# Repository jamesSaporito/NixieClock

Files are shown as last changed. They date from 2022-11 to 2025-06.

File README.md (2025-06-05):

# Nixie Clock Overview

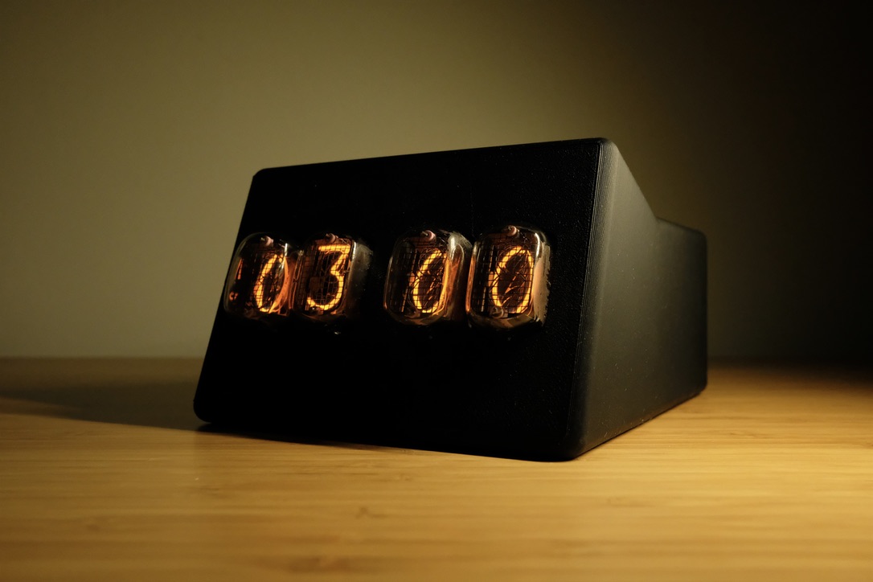
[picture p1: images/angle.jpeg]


This is a nixie tube clock that tells basic time. Two push buttons are used to set the time, one for the hour and the
other for the minute, and a mechanical switch turns the tubes on and off.

More info about [Nixie Tubes](https://en.wikipedia.org/wiki/Nixie_tube).

# Core Components

Four IN-12A nixie tubes are used, which require ~170V DC to illuminate. The
[NCH8200HV](https://omnixie.com/products/nch8200hv-nixie-hv-power-module)
is used to generate this voltage. The mechanical switch cuts power from this module, which allows the tubes to be turned
off.

The nixie tubes are driven from four [K155ID1](https://tubehobby.com/datasheets/k155id1.pdf) ICs, one IC per tube. These are very obsolete, but were made
specifically to drive nixie tubes. The microcontroller used for this project is the [STM32L010K4T6](https://www.st.com/en/microcontrollers-microprocessors/stm32l010k4.html), an Arm
Cortex-M0+ MCU. The RTC is used along with an external 32.768 kHz crystal to keep accurate time. Based on the one I've
built, it consistently gains around two seconds per day.

# PCB

The PCBs were designed using KiCad in two separate projects. These are found in the `pcb` directory.

There are two PCBs, the main board and the tube board. The main board is where all the main components live (MCU, ICs,
capacitors, etc.). The tube board is specifically for the tube sockets to be soldered to, and then the tubes to plug
into those. The main board and tube board plug into each other via header pins. The male header pins are soldered to one
board, and the female to the other. This is how the current flows from the main board to the tube board. It also allows
the PCBs to be disassembled if necessary.

## Notes

The tubes should not be directly soldered to the PCB. Instead, solder [tube sockets](https://www.amazon.com/Pieces-0-039inch-Diameter-Socket-Female/dp/B09D2VQR3Q?th=1)
to the PCB, then plug the tubes into those. This will allow replacement of a tube if one breaks.

# Enclosure

The `3d` directory contains the files for 3D printing an enclosure for the completely assembled clock. These parts
require [threaded brass inserts](https://www.amazon.com/gp/product/B07HKT5W7S/ref=ppx_yo_dt_b_asin_title_o04_s00?ie=UTF8&psc=1) for the screws to secure everything. There are currently two versions of the
enclosure.

## V1
Original design.

Screws are `M2.5 x 5` and `M2.5 x 8`.

The `PCB Spacers` are used for additional support between the boards to minimize stress on the header pins that connect
the tube board to the main board. Three of these spacers can be mounted while screwing the boards onto the front plate.

## V2
Inspired from Dieter Rams's design of the Braun DN40.

All screws are `M2.5 x 5`.

Four screws (top two alone are enough) can be used to secure the tube board to the `PCB Mount`. Easy to tap/screw
directly into the plastic.

The rest of the eight screws require the threaded brass inserts.

## Design Flaws

Due to the PCB using a Tag-Connect footprint for programming, the enclosure design pretty much requires the MCU to be
programmed prior to assembling everything. If there is a desire to upload different firmware, then it will mostly have
to be taken apart.

The DC jack that was used for this design requires to be mounted prior to soldering the wires to it. This restricts the
enclosure from being completely removed without cutting the wires to this jack.

# Firmware

The firmware is a standard STM32 project set up using CLion and its integration with STM32CubeMX.

The only important thing to keep some form of is the `cycle()` function, which is found in `Core/Src/nixie_display.c`.
All this does is cycle through each number on every tube, which is supposed to prevent cathode poisoning. Unsure how
effective this is at the current frequency and duration.

## Programming the MCU

In order to avoid additional hardware, a
[Tag-Connect](https://www.tag-connect.com/product/tc2030-idc-6-pin-tag-connect-plug-of-nails-spring-pin-cable-with-legs)
footprint is used on the main board. This is used with an
[ST-LINK](https://www.st.com/en/development-tools/st-link-v2.html)
device (clones should work just fine) to program the MCU.

### Issues

_Update: It looks like this issue was fixed, I have not had time to test it out._

Unfortunately, using 
[stlink](https://github.com/stlink-org/stlink)
doesn't seem to work with
[several STM32L0xxx MCUs](https://github.com/stlink-org/stlink/issues/1203).
To get around this, the project can be opened up in STM32CubeIDE and flashed using the built in debugging functionality.
Not ideal, but it works.

* STLink GitHub issue: [1203](https://github.com/stlink-org/stlink/issues/1203)

# Images

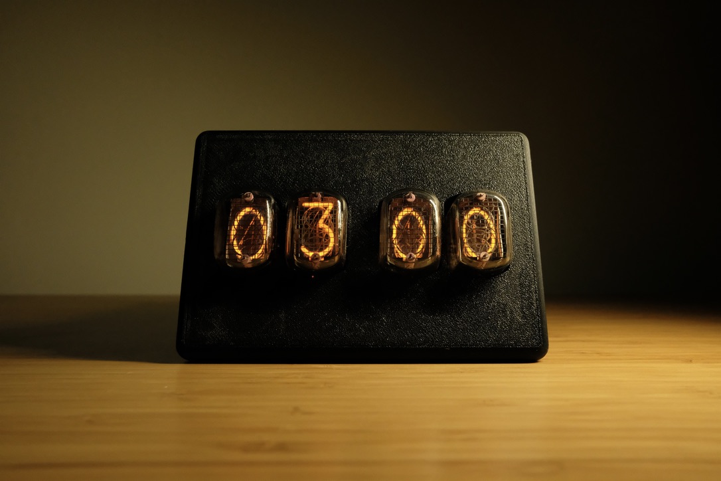
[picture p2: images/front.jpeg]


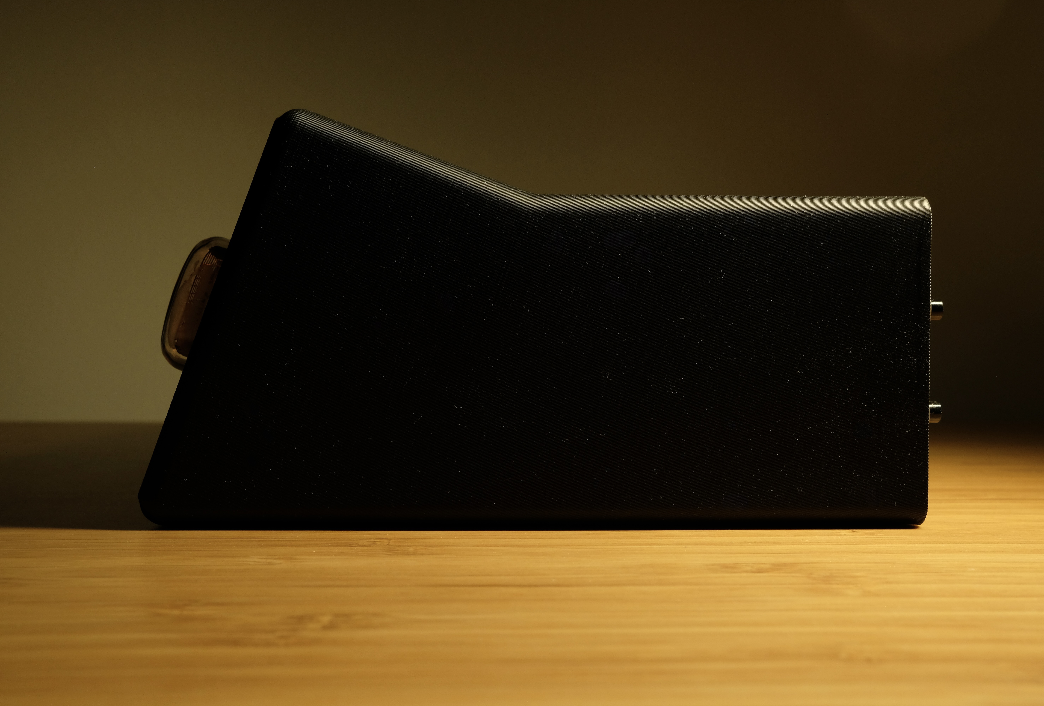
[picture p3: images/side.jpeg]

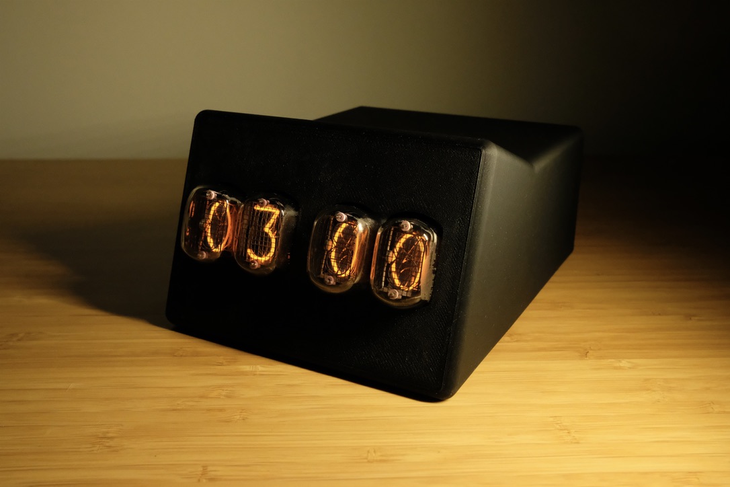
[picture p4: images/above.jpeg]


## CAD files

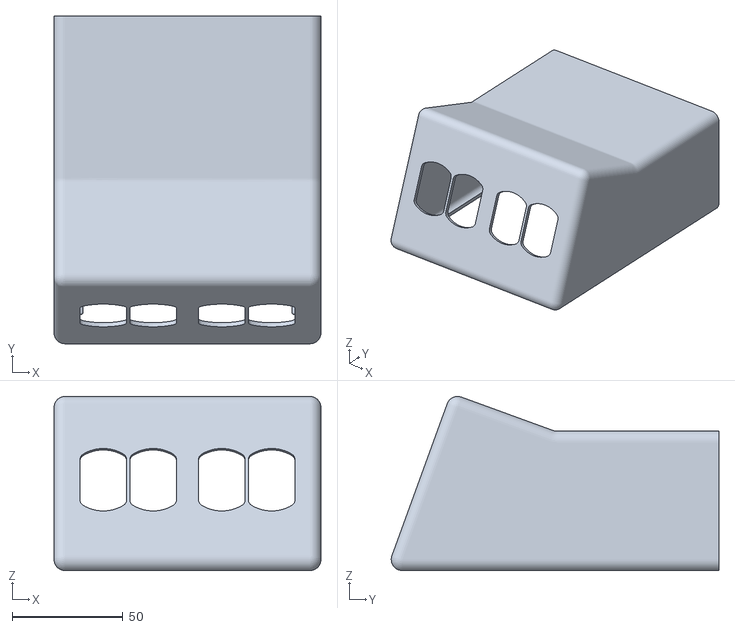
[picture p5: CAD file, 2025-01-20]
3d/v2/Main Body.stl
120.5 x 147.9 x 78.6

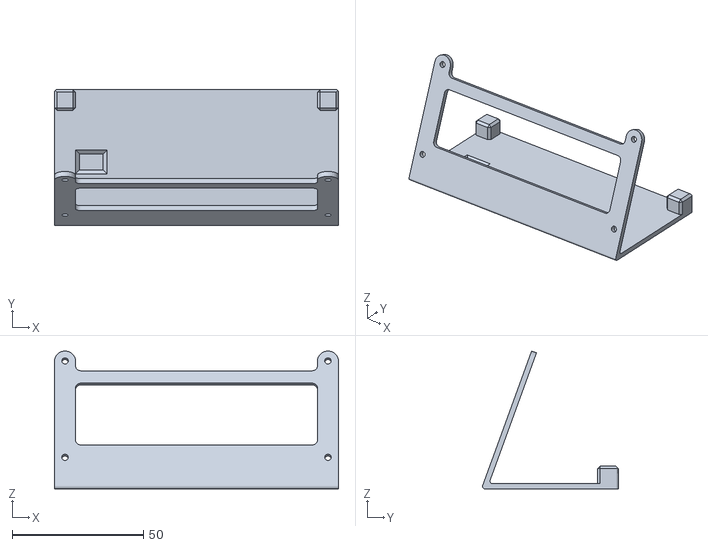
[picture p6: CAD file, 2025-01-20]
3d/v2/PCB Mount.stl
108.0 x 51.7 x 52.4

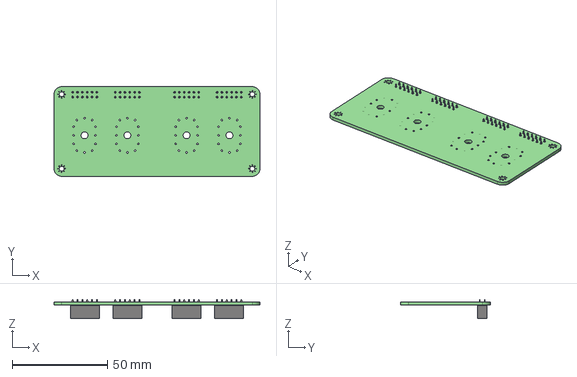
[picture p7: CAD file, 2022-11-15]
pcb/tube_board/Tube Board.step
108.0 x 47.0 x 10.1 mm
Tube Board PCB

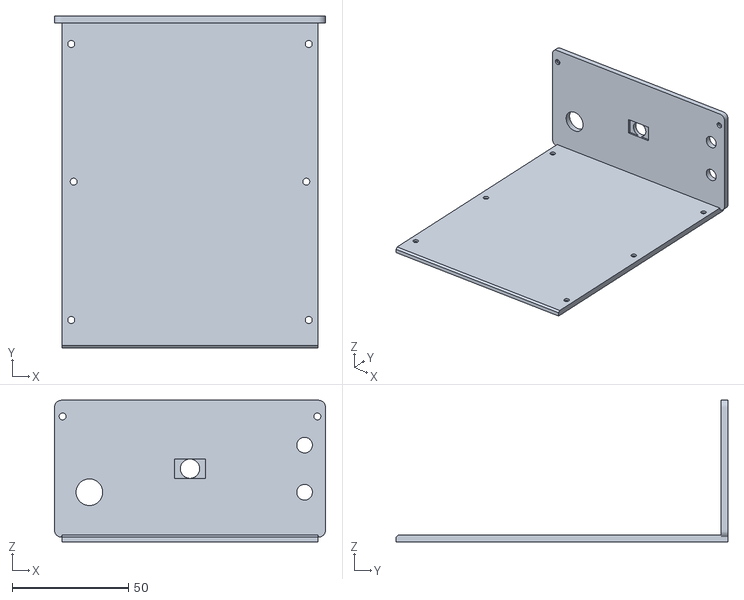
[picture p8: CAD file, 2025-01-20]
3d/v2/Bottom.stl
116.5 x 142.7 x 60.9

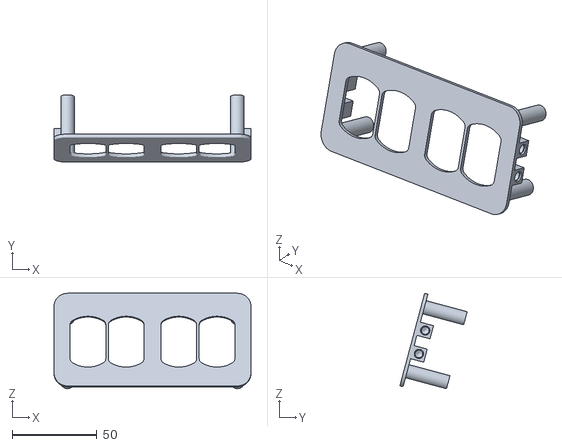
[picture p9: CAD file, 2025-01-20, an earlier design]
3d/v1/Front Plate.stl
116.0 x 39.7 x 56.2

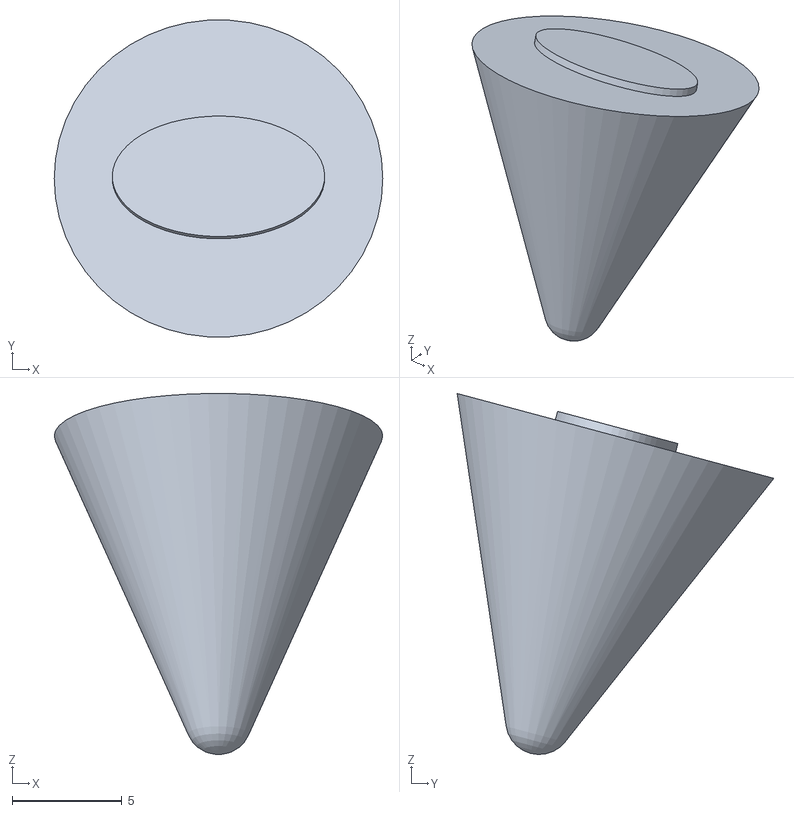
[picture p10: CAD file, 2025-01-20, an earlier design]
3d/v1/Leg.stl
15.0 x 14.5 x 16.5

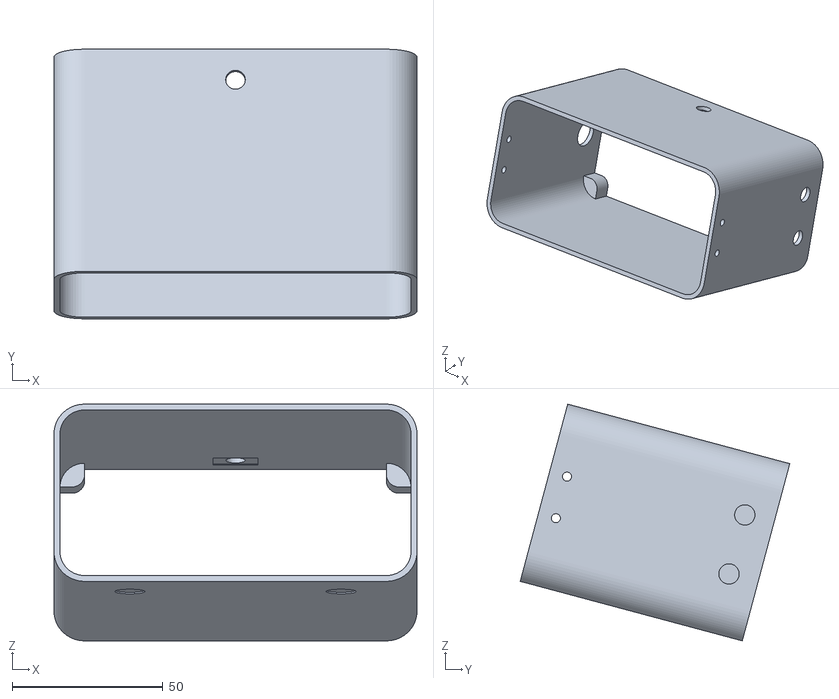
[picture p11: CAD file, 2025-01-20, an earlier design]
3d/v1/Shell.stl
120.3 x 89.3 x 78.5

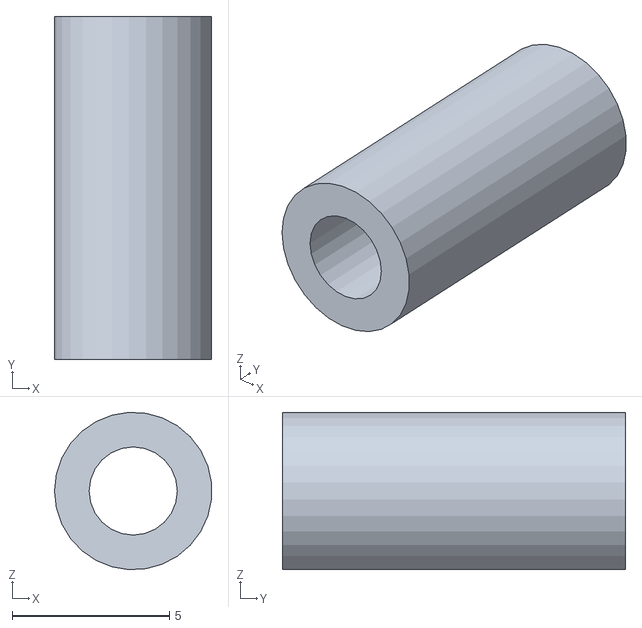
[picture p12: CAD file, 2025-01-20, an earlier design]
3d/v1/Spacer.stl
4.99 x 10.9 x 4.99

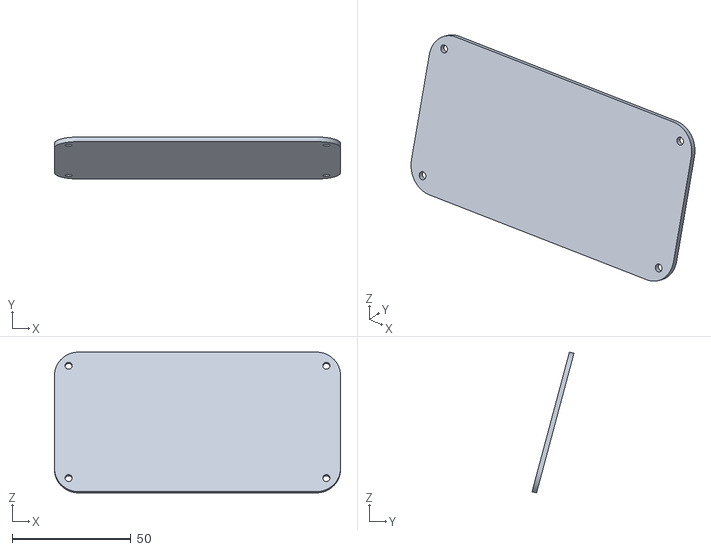
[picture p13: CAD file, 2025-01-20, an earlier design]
3d/v1/Back Plate.stl
120.3 x 17.7 x 59.2

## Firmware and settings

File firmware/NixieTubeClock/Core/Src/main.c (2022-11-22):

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
/* Includes ------------------------------------------------------------------*/
#include "main.h"

RTC_HandleTypeDef hrtc;

/* USER CODE BEGIN PV */

/**
 * Current minute/hour to know when to change the time on the nixie tubes.
 * This is just a copy of what the RTC values are.
 */
uint8_t current_minute = 0;
uint8_t current_hour = 0;

/* USER CODE END PV */

void SystemClock_Config(void);
static void MX_GPIO_Init(void);
static void MX_RTC_Init(void);
/**
  * @brief  The application entry point.
  * @retval int
  */
int main(void)
{
  /* MCU Configuration--------------------------------------------------------*/

  /* Reset of all peripherals, Initializes the Flash interface and the Systick. */
  HAL_Init();

  /* Configure the system clock */
  SystemClock_Config();

  /* Initialize all configured peripherals */
  MX_GPIO_Init();
  MX_RTC_Init();
  /* Infinite loop */
  /* USER CODE BEGIN WHILE */
  while (1)
  {
      /**
       * Although the date isn't used anywhere, you have to read it in
       * order to get the time.
       */
      HAL_RTC_GetTime(&hrtc, &time, RTC_FORMAT_BCD);
      HAL_RTC_GetDate(&hrtc, &date, RTC_FORMAT_BCD);

      /**
       * Only update the tubes if the RTC minute or hour has changed
       */
      if (current_minute != time.Minutes || current_hour != time.Hours) {
          current_minute = time.Minutes;
          current_hour = time.Hours;
          display_time();
      }

      /**
       * Avoid cathode poisoning by occasionally cycling through the numbers.
       */
      if (check_cycle()) {
          cycle();
          display_time();
      }

    /* USER CODE END WHILE */

    /* USER CODE BEGIN 3 */
  }
  /* USER CODE END 3 */
}

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
/* USER CODE BEGIN 4 */

void set_initial_time(void)
{
    time.Hours = 0x12;
    time.Minutes = 0x00;
    time.Seconds = 0x00;
    time.TimeFormat = RTC_HOURFORMAT12_PM;
    HAL_RTC_SetTime(&hrtc, &time, RTC_FORMAT_BCD);
}

void increment_minute(void)
{
    time.Seconds = 0x00;
    if (time.Minutes == 0x59) {
        time.Minutes = 0x00;
    } else {
        time.Minutes = RTC_ByteToBcd2(RTC_Bcd2ToByte(time.Minutes) + 0x01);
    }

    HAL_RTC_SetTime(&hrtc, &time, RTC_FORMAT_BCD);
}

void increment_hour(void)
{
    time.Seconds = 0x00;
    if (time.Hours == 0x12) {
        time.Hours = 0x01;
    } else {
        time.Hours = RTC_ByteToBcd2(
                RTC_Bcd2ToByte(time.Hours) + 0x01
        );
    }

    HAL_RTC_SetTime(&hrtc, &time, RTC_FORMAT_BCD);
}

/**
 * Interrupt to set flag, which allows the main loop to increment the hour or minute
 */
void HAL_GPIO_EXTI_Callback(uint16_t GPIO_Pin)
{
    switch (GPIO_Pin) {
        case GPIO_PIN_1:
            increment_hour();
            break;
        case GPIO_PIN_2:
            increment_minute();
            break;
        default:
            break;
    }
}

/* USER CODE END 4 */
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


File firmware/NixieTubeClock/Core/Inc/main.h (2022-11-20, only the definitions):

#define Minute_Increment_Pin GPIO_PIN_1
#define Minute_Increment_GPIO_Port GPIOA
#define Minute_Increment_EXTI_IRQn EXTI0_1_IRQn
#define Hour_Increment_Pin GPIO_PIN_2
#define Hour_Increment_GPIO_Port GPIOA
#define Hour_Increment_EXTI_IRQn EXTI2_3_IRQn
#define NX1_C_Pin GPIO_PIN_3
#define NX1_C_GPIO_Port GPIOA
#define NX1_B_Pin GPIO_PIN_4
#define NX1_B_GPIO_Port GPIOA
#define NX1_D_Pin GPIO_PIN_5
#define NX1_D_GPIO_Port GPIOA
#define NX1_A_Pin GPIO_PIN_6
#define NX1_A_GPIO_Port GPIOA
#define NX2_C_Pin GPIO_PIN_7
#define NX2_C_GPIO_Port GPIOA
#define NX2_B_Pin GPIO_PIN_0
#define NX2_B_GPIO_Port GPIOB
#define NX2_D_Pin GPIO_PIN_1
#define NX2_D_GPIO_Port GPIOB
#define NX2_A_Pin GPIO_PIN_8
#define NX2_A_GPIO_Port GPIOA
#define NX3_C_Pin GPIO_PIN_9
#define NX3_C_GPIO_Port GPIOA
#define NX3_B_Pin GPIO_PIN_10
#define NX3_B_GPIO_Port GPIOA
#define NX3_D_Pin GPIO_PIN_11
#define NX3_D_GPIO_Port GPIOA
#define NX3_A_Pin GPIO_PIN_12
#define NX3_A_GPIO_Port GPIOA
#define NX4_C_Pin GPIO_PIN_15
#define NX4_C_GPIO_Port GPIOA
#define NX4_B_Pin GPIO_PIN_3
#define NX4_B_GPIO_Port GPIOB
#define NX4_D_Pin GPIO_PIN_4
#define NX4_D_GPIO_Port GPIOB
#define NX4_A_Pin GPIO_PIN_5
#define NX4_A_GPIO_Port GPIOB

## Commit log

2022-11-15 Renaming directory to 3d
    [Back Plate.3mf, Front Plate.3mf, Leg.3mf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]
2022-11-22 Refactoring display functions to use bit set/reset registers directly. Other minor adjustments and adding to README.
    [main.c, nixie_display.c]
2025-01-20 Adjusting README, removing 3mf files, adding both v1 and v1 step files.
    [Back Plate.3mf, Back Plate.stl, Bottom.stl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]
2025-06-05 Adding images and updating README.
    [NixieSTM32.kicad_pcb, NixieSTM32.kicad_sch]

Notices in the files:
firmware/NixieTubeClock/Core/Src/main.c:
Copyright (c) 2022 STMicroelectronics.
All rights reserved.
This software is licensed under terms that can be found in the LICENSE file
